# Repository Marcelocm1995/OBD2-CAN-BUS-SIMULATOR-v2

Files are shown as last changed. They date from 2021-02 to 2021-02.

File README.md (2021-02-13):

# OBD2-CAN-Simulator-v2
This project is a new version of OBD2 CAN Simulator that simulates CAN BUS of OBD2 port, helping to develop OBD2 CAN BUS projects.

# What Changes
Now this project have a GUI that user can especify sensor values (last version works with random values).
Multiple PID request in one message, like a real ECU!

# How It Works:
This project get the second byte of data of received CAN message and determine the size of reponse, then return values(selected on GUI) on fourth-seventh data of CAN message.
To read OBD protocol our device need to have an ID = 0x7DF, ECM will return with ID = 0x7E8. Knowing this, we configure CAN filter to receive only ID = 0x7E8, with this filter any other ID will be ignored.

# Software:
It uses cubeMX for generate a pre-code. Compiler Keil uVision, but you can easily migrate to another suported compiler by cubeMX, like IAR.
For GUI it uses Nextion Editor.
NOTE: in folder "CAN_simulator" have an archive "Drivers.zip", you need to extract.

# Hardware:
This hardware uses a STM32F103C8T6 (bluepill board) with a CAN transceiver (MCP2251).
MCP2551 is 5V logic, because of that we need to use PB9 and PB8 pins (this pins are 5V tolerant). Pins PA11 and PA12 aren't 5V tolerant.
The display for GUI is a Nextion NX4024T032_11 connected on USART3 (PB10 and PB11).

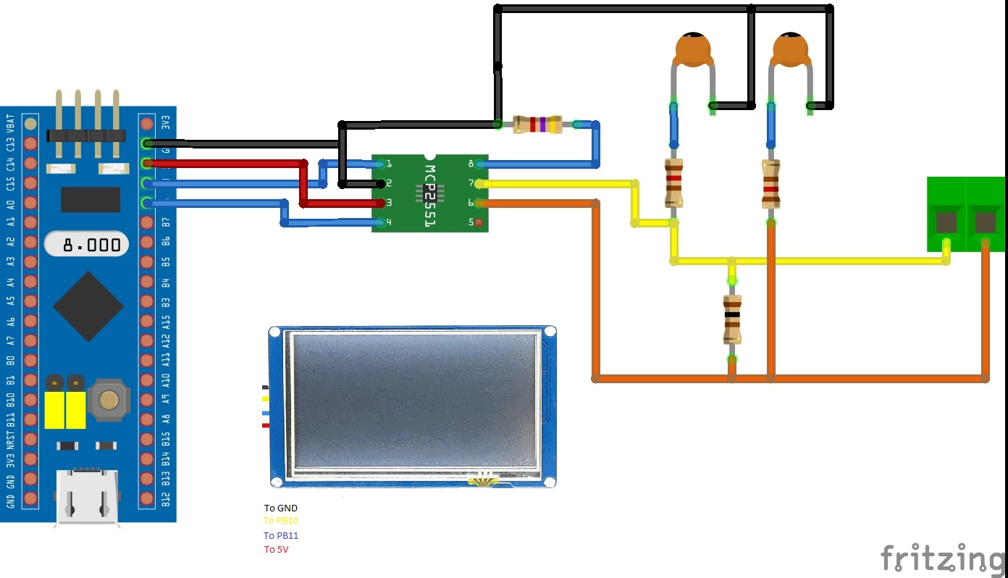
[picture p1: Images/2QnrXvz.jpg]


# CAN SPEED
Clock was configured at 72MHz, with this clock we set: 
* CAN preescaler = 9
* Time Quantum in Bit Segment 1 = 3TQ
* Time Quantum in Bit Segment 2 = 4TQ

This configuration gives a CAN speed = 500kbps, 2uS for each bit (most commom on OBD2).

# Enclosure
I made a 3D printed enclosure for this project, STL's and STEP's are avaiable for download on this repository.
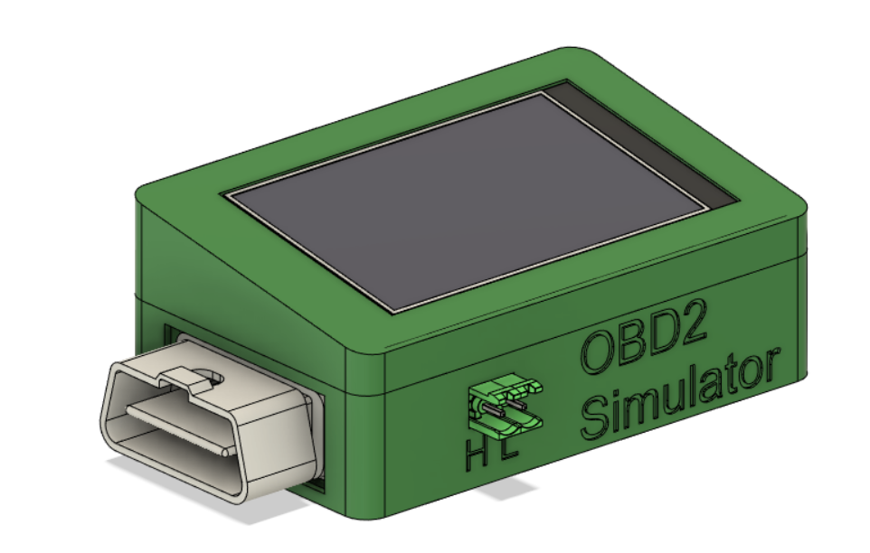
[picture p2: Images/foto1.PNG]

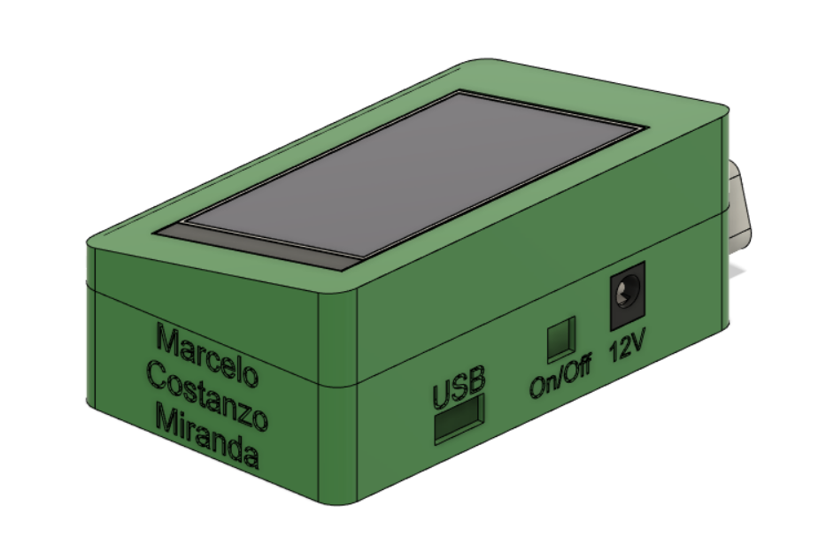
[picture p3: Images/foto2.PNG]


# Final project
IMAGE ALT TEXT HERE (https://www.youtube.com/watch?v=TzrFJ_mD2jE)

https://www.youtube.com/watch?v=TzrFJ_mD2jE

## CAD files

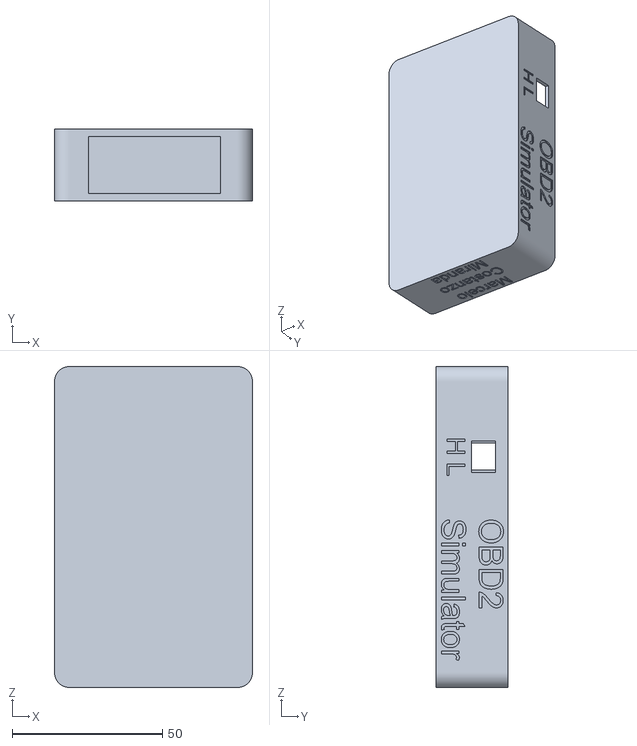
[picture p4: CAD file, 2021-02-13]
3D Print/STL/case_obd_simu_nextion.stl
66.0 x 24.0 x 107.0

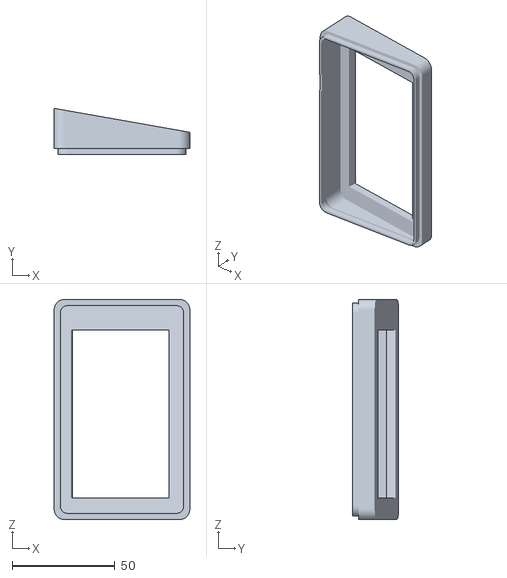
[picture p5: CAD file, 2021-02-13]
3D Print/STL/tampa_obd_simu_nextion.stl
66.0 x 22.5 x 107.0

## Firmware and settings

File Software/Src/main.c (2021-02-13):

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

/* Includes ------------------------------------------------------------------*/
#include "main.h"

/* USER CODE BEGIN Includes */
#include "stdio.h"
#include "string.h"
#include "stdbool.h"
#include "PIDs.h"

/* USER CODE END Includes */

/* USER CODE BEGIN PD */

#define NUMBER_OF_RX_PIDs canRX[0]
#define NUMBER_OF_TX_PIDs canTX_msg[1]

#define FIRST_RX_PID canRX[2]
#define SECOND_RX_PID canRX[3]
#define THIRD_RX_PID canRX[4]

#define ONE_PID 0x02
#define TWO_PID 0x03
#define THREE_PID 0x04

#define RX_ID 0x7DF
#define TX_ID 0x7E8

/* USER CODE END PD */

CAN_HandleTypeDef hcan;

UART_HandleTypeDef huart3;

/* USER CODE BEGIN PV */

CAN_RxHeaderTypeDef rxHeader;
CAN_TxHeaderTypeDef txHeader;

CAN_FilterTypeDef canfil;

uint32_t canMailbox;

uint8_t canRX[8];
uint8_t canTX[8];

uint8_t canTX_msg[8]; //create CAN TX data message

uint8_t Rx_Nextion[20];
bool NextionRxMsg = 0;

uint8_t PAGE_NEXTION;

uint8_t INTAKE_PRESSURE, 
				INTAKE_TEMPERATURE,
				ENGINE_COOLANT,
				LAMBDA_NARROW,
				LAMBDA_WIDE_1,
				LAMBDA_WIDE_2,
				LAMBDA_WIDE_3,
				IGNITION_TIMING,
				THROTTLE_POS;
				
uint16_t	FUEL_RAIL;

/* USER CODE END PV */

void SystemClock_Config(void);
static void MX_GPIO_Init(void);
static void MX_CAN_Init(void);
static void MX_USART3_UART_Init(void);
/* USER CODE BEGIN PFP */

float Map (float inVal, float inMin, float inMax, float outMin, float outMax);
void filter_can_config(void);
//void send_canmsg(unsigned char pid);
void send_canmsg(void);
void HAL_CAN_RxFifo0MsgPendingCallback(CAN_HandleTypeDef *hcan);
void Parse_Nextion(void);
void parse_data(unsigned char pid, uint8_t *A, uint8_t *B, uint8_t *C, uint8_t *D, uint8_t *size);
void Page_0(void);
void Page_1(void);
void Page_2(void);
/* USER CODE END PFP */

/**
  * @brief  The application entry point.
  * @retval int
  */
int main(void)
{
  /* MCU Configuration--------------------------------------------------------*/

  /* Reset of all peripherals, Initializes the Flash interface and the Systick. */
  HAL_Init();

  /* Configure the system clock */
  SystemClock_Config();

  /* USER CODE BEGIN SysInit */
	HAL_Delay(5000);
  /* USER CODE END SysInit */

  /* Initialize all configured peripherals */
  MX_GPIO_Init();
  MX_CAN_Init();
  MX_USART3_UART_Init();
  /* USER CODE BEGIN 2 */
	
	HAL_UART_Receive_IT(&huart3, Rx_Nextion, 11);
	
	/*----Config filter and start CAN interface------*/
	filter_can_config();
	HAL_CAN_ConfigFilter(&hcan, &canfil);
	HAL_CAN_Start(&hcan);
	//HAL_CAN_ActivateNotification(&hcan, CAN_IT_RX_FIFO0_MSG_PENDING);
	
	/*----Configure CAN TX messages------------*/
	txHeader.DLC = 8;
	txHeader.IDE = CAN_ID_STD;
	txHeader.RTR = CAN_RTR_DATA;
	txHeader.StdId = TX_ID;
	txHeader.ExtId = 0x02;
	txHeader.TransmitGlobalTime = DISABLE;
	
	HAL_GPIO_WritePin(LED1_GPIO_Port, LED1_Pin, GPIO_PIN_SET);
	
	HAL_CAN_ActivateNotification(&hcan, CAN_IT_RX_FIFO0_MSG_PENDING);
  /* USER CODE END 2 */

  /* Infinite loop */
  /* USER CODE BEGIN WHILE */
  while (1)
  {
		if(NextionRxMsg == 1)
		{
			Parse_Nextion();
			NextionRxMsg = 0;
		}

    if(rxHeader.StdId == RX_ID) //Verify if RX ID is 0x7DF
    {
				//Create_CAN_Msg();
				//send_canmsg(canRX[2]);  //Call function that send CAN message
				send_canmsg();					//Call function that send CAN message
				rxHeader.StdId = 0x00;	//Clear RX ID for don't enter in this "if" on next loop
				HAL_Delay(50);					//Some delay for my application not go to fast, we can comment this line for faster messages
		}
		
    /* USER CODE END WHILE */

    /* USER CODE BEGIN 3 */
  }
  /* USER CODE END 3 */
}

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
/* USER CODE BEGIN 4 */

void HAL_UART_RxCpltCallback(UART_HandleTypeDef *huart)
{
	NextionRxMsg = 1;
	HAL_UART_Receive_IT(&huart3, Rx_Nextion, 11);
}

void HAL_CAN_RxFifo0MsgPendingCallback(CAN_HandleTypeDef *hcan)
{
	HAL_CAN_GetRxMessage(hcan, CAN_RX_FIFO0, &rxHeader, canRX); //Receive CAN bus message to canRX buffer in INTERRUPT MODE
	HAL_GPIO_TogglePin(LED1_GPIO_Port, LED1_Pin);// toggle PC13 LED
}

void Page_0()
{
	switch (Rx_Nextion[2])
	{
		case 1: INTAKE_PRESSURE = Rx_Nextion[7]; break;
		case 2: INTAKE_TEMPERATURE = Rx_Nextion[7]; break;
		case 3: ENGINE_COOLANT = Rx_Nextion[7]; break;
		case 4: LAMBDA_NARROW = Rx_Nextion[7]; break;
		case 5: FUEL_RAIL = Rx_Nextion[7] + (Rx_Nextion[8] * 256); break;
	}
}

void Page_1()
{
	switch (Rx_Nextion[2])
	{
		case 1: IGNITION_TIMING = Rx_Nextion[7]; break;
		case 2: THROTTLE_POS = Rx_Nextion[7]; break;
	}
}

void Page_2()
{
	switch (Rx_Nextion[2])
	{
		case 1: ; break;
		case 2: ; break;
	}
}

void Parse_Nextion()
{
	switch (Rx_Nextion[1])
	{
		case 0: Page_0(); break;
		case 1: Page_1(); break;
		case 2: Page_2(); break;
	}
}
	
void send_canmsg()
{
		uint8_t A, B, C, D, SIZE_OF_FIRST_PID, SIZE_OF_SECOND_PID, SIZE_OF_THIRD_PID;
		canTX_msg[0] = 0x41;
	
		if(NUMBER_OF_RX_PIDs == ONE_PID)
		{
			NUMBER_OF_TX_PIDs = NUMBER_OF_RX_PIDs;
			parse_data(FIRST_RX_PID, &A, &B, &C, &D, &SIZE_OF_FIRST_PID);
			canTX_msg[2] = FIRST_RX_PID;
			canTX_msg[3] = A;
			canTX_msg[4] = B;
			canTX_msg[5] = C;
			canTX_msg[6] = D;		
			canTX_msg[7] = NULL;			
		}
		
		if(NUMBER_OF_RX_PIDs == TWO_PID)
		{
			NUMBER_OF_TX_PIDs = NUMBER_OF_RX_PIDs;
			canTX_msg[2] = FIRST_RX_PID;
			parse_data(FIRST_RX_PID, &A, &B, &C, &D, &SIZE_OF_FIRST_PID);
			if(SIZE_OF_FIRST_PID == 2)
			{
				canTX_msg[3] = A;
				canTX_msg[4] = B;
				canTX_msg[5] = SECOND_RX_PID;
				parse_data(SECOND_RX_PID, &A, &B, &C, &D, &SIZE_OF_SECOND_PID);
				canTX_msg[6] = A;
				canTX_msg[7] = B;	
			}
			else
			{
				canTX_msg[3] = A;
				canTX_msg[4] = SECOND_RX_PID;
				parse_data(SECOND_RX_PID, &A, &B, &C, &D, &SIZE_OF_SECOND_PID);
				canTX_msg[5] = A;
				canTX_msg[6] = B;	
				canTX_msg[7] = NULL;	
			}
		}
		
		if(NUMBER_OF_RX_PIDs == THREE_PID)
		{
			NUMBER_OF_TX_PIDs = NUMBER_OF_RX_PIDs;
			canTX_msg[2] = FIRST_RX_PID;
			parse_data(FIRST_RX_PID, &A, &B, &C, &D, &SIZE_OF_FIRST_PID);
			if(SIZE_OF_FIRST_PID == 2)
			{
				canTX_msg[3] = A;
				canTX_msg[4] = B;
				canTX_msg[5] = SECOND_RX_PID;
				parse_data(SECOND_RX_PID, &A, &B, &C, &D, &SIZE_OF_SECOND_PID);
				canTX_msg[6] = A;
				canTX_msg[7] = B;	
			}
			else
			{
				canTX_msg[3] = A;
				canTX_msg[4] = SECOND_RX_PID;
				parse_data(SECOND_RX_PID, &A, &B, &C, &D, &SIZE_OF_SECOND_PID);
				if(SIZE_OF_SECOND_PID == 2)
				{
					canTX_msg[5] = A;
					canTX_msg[6] = B;	
					canTX_msg[7] = NULL;	
				}
				else
				{
					canTX_msg[5] = A;
					canTX_msg[6] = THIRD_RX_PID;
					parse_data(THIRD_RX_PID, &A, &B, &C, &D, &SIZE_OF_THIRD_PID);
					canTX_msg[7] = A;
				}
			}
		}
		
		HAL_CAN_AddTxMessage(&hcan, &txHeader, canTX_msg, &canMailbox);//send TX CAN message
	
		memset(canTX_msg, 0x00, 8);
		HAL_GPIO_TogglePin(LED1_GPIO_Port, LED1_Pin);// toggle PC13 LED
}

void parse_data(unsigned char pid, uint8_t *A, uint8_t *B, uint8_t *C, uint8_t *D, uint8_t *size)
{
    switch (pid) 
    {
        case PID_RPM:
        case PID_EVAP_SYS_VAPOR_PRESSURE: // kPa
            break;
        case PID_FUEL_PRESSURE: // kPa
            break;
        case PID_COOLANT_TEMP: //celsius
            *A = ENGINE_COOLANT; *B = 0x00; *C = 0x00; *D = 0x00; *size = 1;
            break;
        case PID_OXYGEN_SENSOR: //milivolts
            *A = LAMBDA_NARROW;  *B = 0x00; *C = 0x00; *D = 0x00; *size = 2;
            break;
        case PID_INTAKE_TEMP: //celsius
            *A = INTAKE_TEMPERATURE; *B = 0x00; *C = 0x00; *D = 0x00; *size = 1;
            break;
        case PID_INTAKE_MAP: //kpa
            *A = INTAKE_PRESSURE; *B = 0x00; *C = 0x00; *D = 0x00; *size = 1;
            break;
        case PID_AMBIENT_TEMP:
        case PID_ENGINE_OIL_TEMP://celsius
            break;
        case PID_THROTTLE: //percent
            *A = THROTTLE_POS; *B = 0x00; *C = 0x00; *D = 0x00; *size = 1;
            break;
        case PID_SPEED: //km/h
            break;
        case PID_COMMANDED_EGR:
        case PID_COMMANDED_EVAPORATIVE_PURGE:
        case PID_FUEL_LEVEL:
        case PID_RELATIVE_THROTTLE_POS:
        case PID_ABSOLUTE_THROTTLE_POS_B:
        case PID_ABSOLUTE_THROTTLE_POS_C:
        case PID_ACC_PEDAL_POS_D:
        case PID_ACC_PEDAL_POS_E:
        case PID_ACC_PEDAL_POS_F:
        case PID_COMMANDED_THROTTLE_ACTUATOR:
        case PID_ENGINE_LOAD://percent
            break;
        case PID_ABSOLUTE_ENGINE_LOAD:
        case PID_ETHANOL_FUEL:
        case PID_HYBRID_BATTERY_PERCENTAGE:
        case PID_MAF_FLOW: // grams/sec
            break;
        case PID_TIMING_ADVANCE: //degree
            *A = IGNITION_TIMING; *B = 0x00; *C = 0x00; *D = 0x00; *size = 1;
            break;
        case PID_DISTANCE: // km
        case PID_DISTANCE_WITH_MIL: // km
        case PID_TIME_WITH_MIL: // minute
        case PID_TIME_SINCE_CODES_CLEARED: // minute
        case PID_RUNTIME: // second
        case PID_FUEL_RAIL_PRESSURE:// kPa
            *A = (FUEL_RAIL >> 8) & 0xFF; *B = (FUEL_RAIL >> 0) & 0xFF; *C = 0x00; *D = 0x00; *size = 2;
            break;
        case PID_ENGINE_REF_TORQUE: // Nm
            break;
        case PID_CONTROL_MODULE_VOLTAGE: // V
            break;
        case PID_ENGINE_FUEL_RATE: // L/h
            break;
        case PID_ENGINE_TORQUE_DEMANDED: // %
        case PID_ENGINE_TORQUE_PERCENTAGE: // %
            break;
        case PID_SHORT_TERM_FUEL_TRIM_1:
        case PID_LONG_TERM_FUEL_TRIM_1:
        case PID_SHORT_TERM_FUEL_TRIM_2:
        case PID_LONG_TERM_FUEL_TRIM_2:
        case PID_EGR_ERROR:
            break;
        case PID_FUEL_INJECTION_TIMING:
            break;
        case PID_CATALYST_TEMP_B1S1:
        case PID_CATALYST_TEMP_B2S1:
        case PID_CATALYST_TEMP_B1S2:
        case PID_CATALYST_TEMP_B2S2:
            break;
        case PID_AIR_FUEL_EQUIV_RATIO_1: // 0~200
            break;
				case PID_AIR_FUEL_EQUIV_RATIO_2: // 0~200
            break;
				case PID_AIR_FUEL_EQUIV_RATIO_3: // 0~200
            break;
        default:
            *A = 0x00; *B = 0x00; *C = 0x00; *D = 0x00; 
    }//fim do case
}

void filter_can_config()
{
	//https://www.esacademy.com/en/library/calculators/can-best-and-worst-case-calculator.html
	//https://schulz-m.github.io/2017/03/23/stm32-can-id-filter/
	canfil.FilterBank = 0;
	canfil.FilterMode = CAN_FILTERMODE_IDMASK;
	canfil.FilterFIFOAssignment = CAN_RX_FIFO0;

	canfil.FilterIdHigh = ((RX_ID << 5)  | (RX_ID >> (32 - 5))) & 0xFFFF; // STID[10:0] & EXTID[17:13]
	canfil.FilterIdLow = (RX_ID >> (11 - 3)) & 0xFFF8; // EXID[12:5] & 3 Reserved bits
	
	canfil.FilterMaskIdHigh = ((0x1FFFFFFF << 5)  | (0x1FFFFFFF >> (32 - 5))) & 0xFFFF;
  canfil.FilterMaskIdLow = (0x1FFFFFFF >> (11 - 3)) & 0xFFF8;
	
	canfil.FilterScale = CAN_FILTERSCALE_32BIT;
	canfil.FilterActivation = ENABLE;
	canfil.SlaveStartFilterBank = 14;
}

float Map (float inVal, float inMin, float inMax, float outMin, float outMax)
{
	return ( (inVal - inMin)*(outMax - outMin)/(inMax - inMin) + outMin );
}


/* USER CODE END 4 */
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


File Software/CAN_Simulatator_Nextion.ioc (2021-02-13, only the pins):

Mcu.UserName=STM32F103CBTx
PA13.Signal=SYS_JTMS-SWDIO
PA14.Signal=SYS_JTCK-SWCLK
PB10.Signal=USART3_TX
PB11.Signal=USART3_RX
PB8.Signal=CAN_RX
PB9.Signal=CAN_TX
PC13-TAMPER-RTC.GPIO_Label=LED1
PC13-TAMPER-RTC.Signal=GPIO_Output
PD0-OSC_IN.Signal=RCC_OSC_IN
PD1-OSC_OUT.Signal=RCC_OSC_OUT

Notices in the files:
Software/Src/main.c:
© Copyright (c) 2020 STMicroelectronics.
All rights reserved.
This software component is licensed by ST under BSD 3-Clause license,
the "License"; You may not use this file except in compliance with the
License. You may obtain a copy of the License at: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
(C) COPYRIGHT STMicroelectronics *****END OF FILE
